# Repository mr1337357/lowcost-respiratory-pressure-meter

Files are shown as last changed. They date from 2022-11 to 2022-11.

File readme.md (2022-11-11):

# Low Cost Respiratory Pressure Meter

[Original Paper](https://www.ncbi.nlm.nih.gov/pmc/articles/PMC8427661/#:~:text=The%20MIP%2FMEP%20device%20should,1%2Ds%20average%20maximum%20pressure)

My dad asked me to help him build a device he found in a science paper and I have ideas for how I want to change it. This is a repo for that.

## licenses

Hardware designs are CERN OHL v1.2  
Software designs are GPL v3

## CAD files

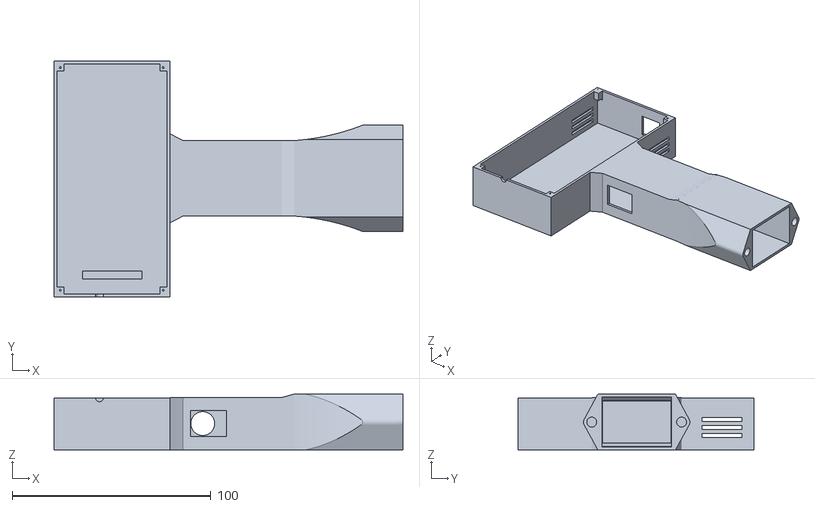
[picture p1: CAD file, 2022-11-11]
printables/electronics case.stl
175.7 x 118.6 x 28.0

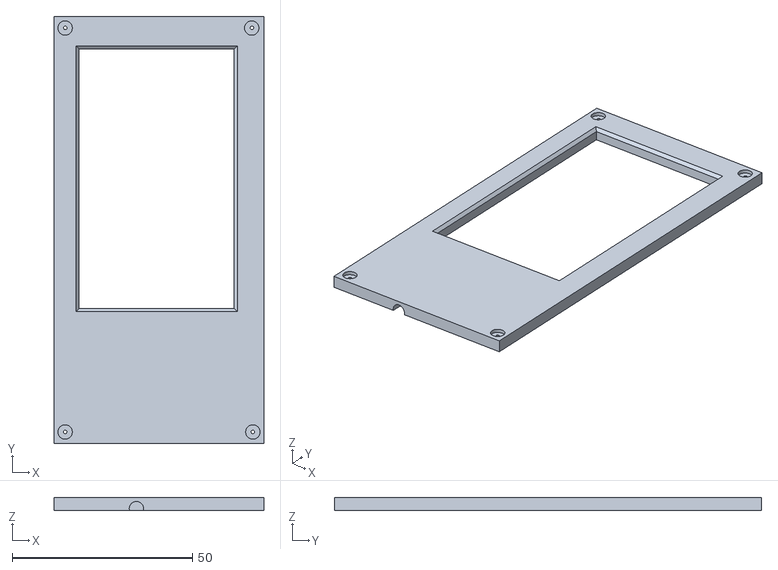
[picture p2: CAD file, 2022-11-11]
printables/screen bezel.stl
58.3 x 118.6 x 3.50

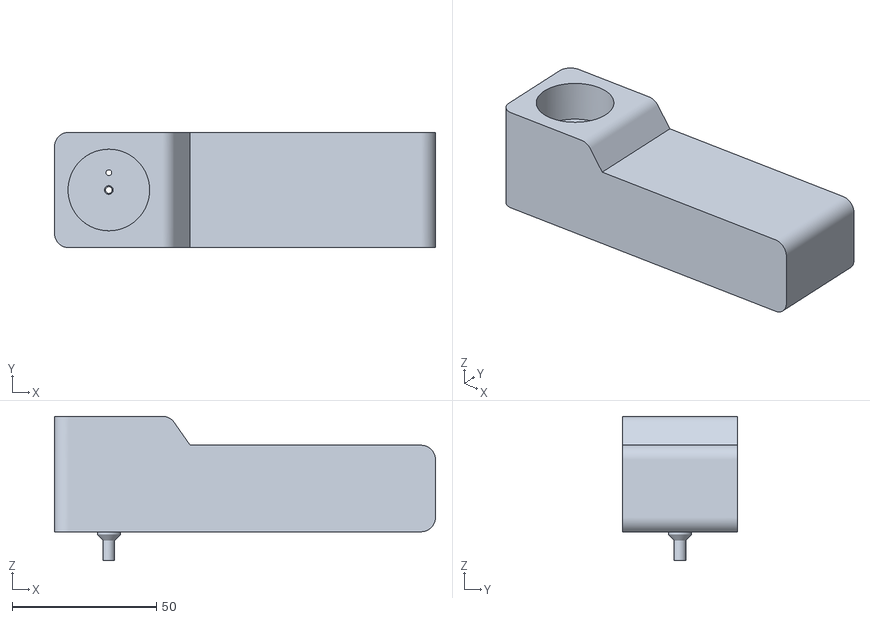
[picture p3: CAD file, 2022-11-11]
printables/handle.stl
132.0 x 40.0 x 50.0

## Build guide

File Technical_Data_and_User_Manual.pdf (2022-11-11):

## OPEN SOURCE HARDWARE PUBLICATION

## TECHNICAL DESCRIPTION

LOW-COST OPEN-SOURCE DEVICE TO MEASURE MAXIMAL

INSPIRATORY AND EXPIRATORY PRESSURES

Claudia Aymerich¹

, Miguel Rodríguez-Lázaro¹

, Gorka Solana²
, Ramon

Farré¹,3,4, Jorge Otero¹,3, *

1 Unitat de Biofísica i Bioenginyeria, Facultat de Medicina i Ciències de la

Salut, Universitat de Barcelona, Barcelona, Spain.

2 Faculdade de Engenharias e Tecnologias, Universidade Save -

Moçambique

3 CIBER de Enfermedades Respiratorias, Madrid, Spain

4
Institut d’Investigacions Biomediques August Pi Sunyer, Barcelona, Spain

*Corresponding author:

Dr. Jorge Otero

Unitat de Biofísica i Bioenginyeria

Facultat de Medicina i Ciències de la Salut

Casanova 143, 08028 Barcelona, Spain

Email: jorge.otero@ub.edu

## LICENSE:

This device is released under CERN Open Hardware License (OHL)

v1.2 and all software and documentation under GNU General Public

License (GPL) v3.0.

Content:

### 1. Device code 2. Schematics of the circuit 3. PCB board layout 4. Connections 5. Enclosure by 3D printer 6. User manual

### 1. Device code

Source code in file: CODE_Arduino.ino (included in the same zip folder where this pdf file is located).

DISCLAIMER

This document provides technical information on the specific device

prototype described in the publication indicated above.

Using components different from (although similar to) the ones described

here may require technical adjustments or adaptations and therefore the

final performance of the resulting device must be specifically assessed.

The authors of this document are not responsible for the use of the

information contained herein nor for any device built using such

information.

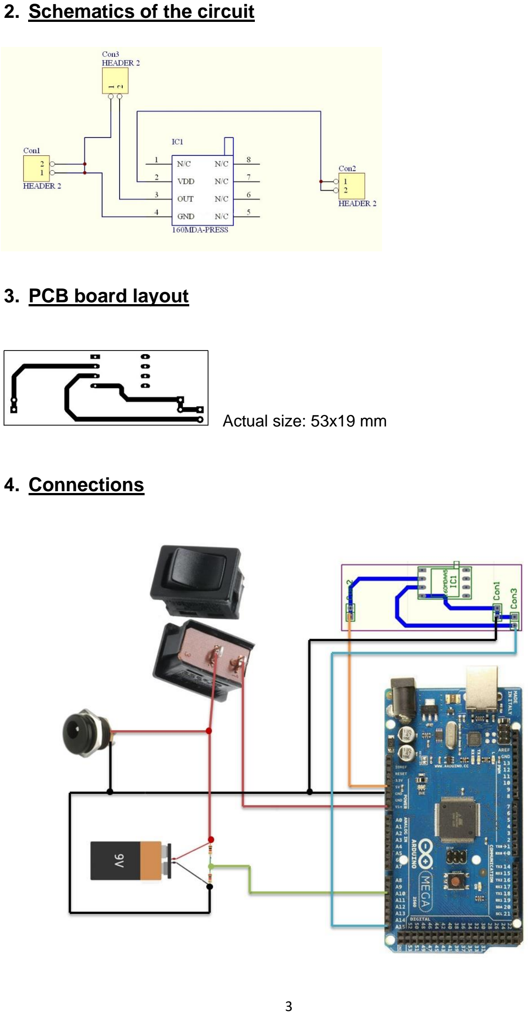
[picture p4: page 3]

### 2. Schematics of the circuit

### 3. PCB board layout

Actual size: 53x19 mm

### 4. Connections

### 5. Enclosure by 3D printing

Source code in files: 3D-file1.stl, 3D-file2.stl, 3D-file3.stl (included in the same zip folder where this pdf file is located).

- Framework

It consists on a rectangular block, adapted to the dimensions of the Arduino, LCD

shield and the PCB, united to the handle block and a cover. The rectangular block

contains some slots for ventilation to avoid the Arduino board overheating, 4 supports

for the screws, 1 support to avoid the Arduino to move, a small slot for the connection

of the transducer to the silicon tube and a hole for the USB type B port of the

Arduino. To optimize the device, it was determined to place the battery in the handle.

The 9V block and its support had perfect dimensions to adapt to this idea. In this

way, the battery could easily be removed from the bottom of the handle. The handle

contains a hole, as well, to place the power switch and another one to place the

supply base. Finally, the cover contains the holes for the screws, the transducer slot

and a rectangular hole adapted to the dimensions of the visible part of the LCD.

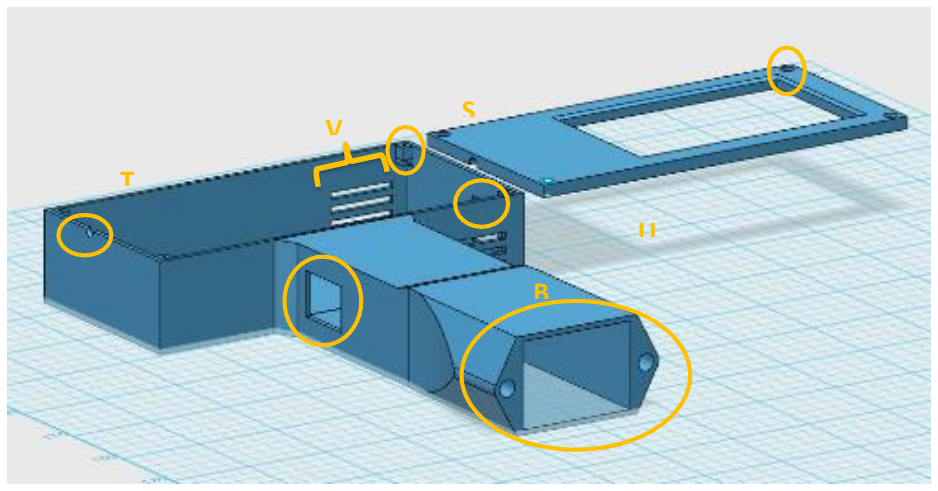
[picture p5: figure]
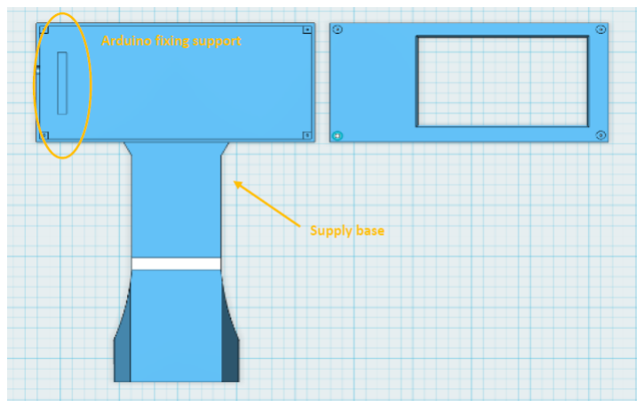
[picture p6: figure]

- Mouthpiece support

It consists of two jointed blocks of different depth. The first block consists on the

handle and the second block is adapted to contain the disposable carton mouthpiece.

Two small holes have been incorporated. The one in the centre connects the air in

the mouthpiece to the transducer along the silicon tube. The second one, on its right,

consist on a small loss of air. It is required to prevent closure of the glottis during

forced inspiration and decreased use of the oral muscles during forced expiration.

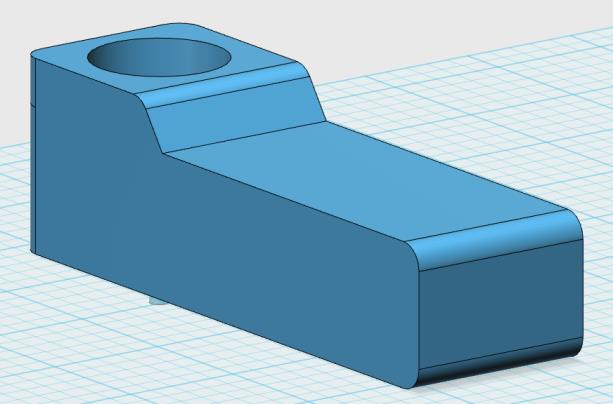
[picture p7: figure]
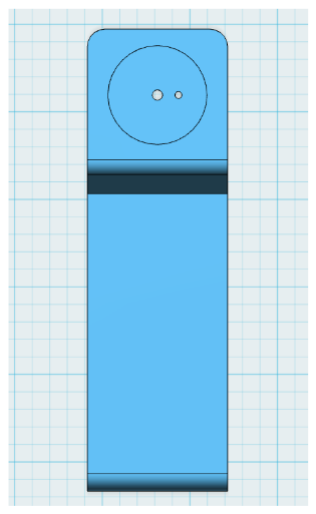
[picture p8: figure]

### 6. User manual

## DEVICE TO MEASURE

## MAXIMAL INSPIRATORY AND EXPIRATORY PRESSURES (MIP / MEP)

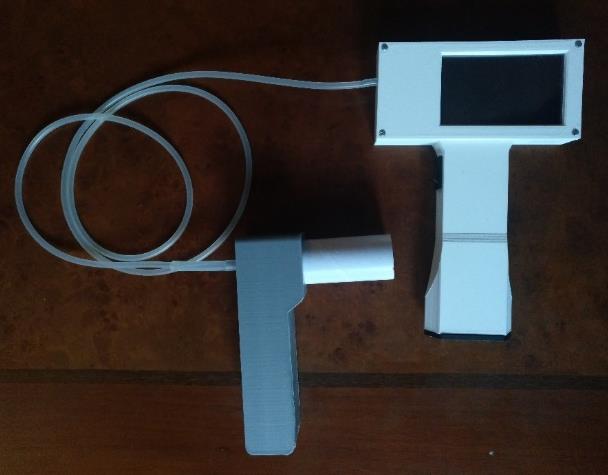
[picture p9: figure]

### 0. Prior instructions

Place a disposable mouthpiece on the corresponding holder and give it to the patient.

### 1. Home screen

Press the switch to start the device. Then, press the button of the test you want to perform. Options to choose from:

-MIP test (Measurement of maximum inspiratory pressure)

-MEP test (Measurement of maximum expiratory pressure)

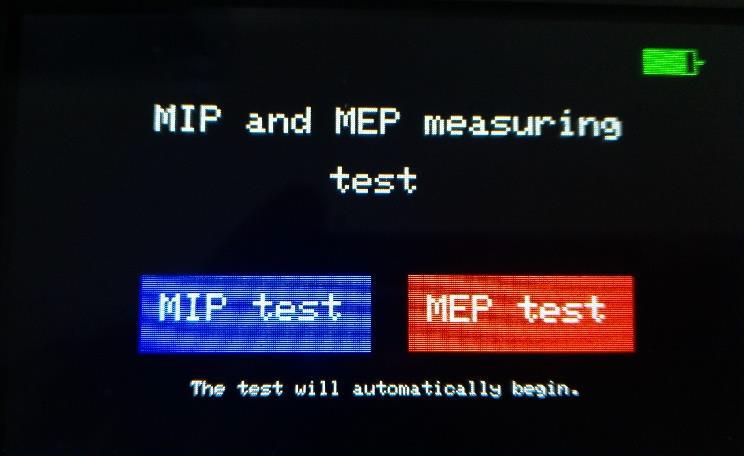
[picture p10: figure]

Figure 1. Home screen

If you choose a wrong button, you will not be able to change the test until step 3.

### 2. Carrying out the test

Have the patient perform the maximum inspiration (or expiration) maneuver. It must last at least 1 second. The maximum time to perform the test is 5 seconds. The screen will display the maximum inspiratory (or expiratory) pressure value of the measurement performed (Figure 2).

If the maneuver has been done correctly, you should observe a curve similar to that in Figure 3. In this case, press the "Accept" button. The measurement will be saved in the device memory. To reject the measurement, press the "Reject" button.

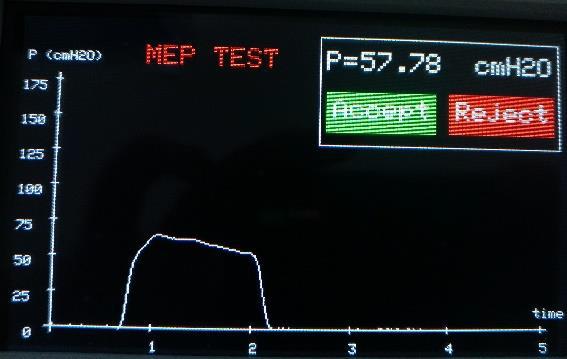
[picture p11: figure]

Figure 2. Test run

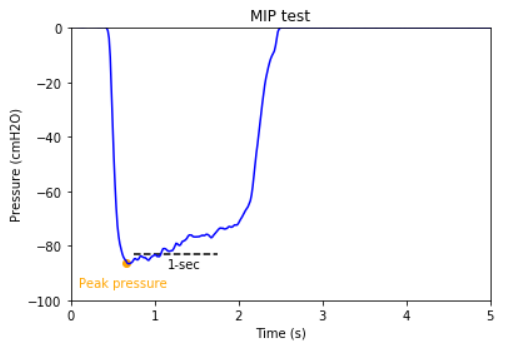
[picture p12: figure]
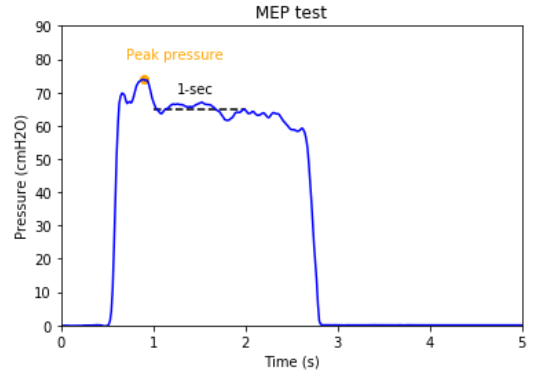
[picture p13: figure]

Figure 3. Illustration of correct MEP (Pemax) and MIP (Pimax) measurements

### 3. Repetition of the test

To perform the next test, press the “Next measure” button and repeat the procedure in point 2. You will see that, as you perform valid tests, the pressure values of the previous measurements will appear on the right side of the screen.

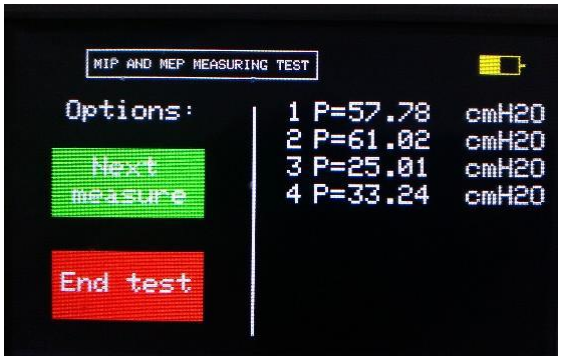
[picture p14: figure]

Figure 4. Screen at the end of a measurement

If you want to change the experiment or end the experiment, press the "End test" button. This button will direct you to step 5.

### 4. Completion of the MIP / MEP test

In the case of performing three measurements that differ by less than 10%, the device will indicate the value of MIP or MEP of that patient, as shown in Figure 5. In addition, at the bottom- on the right side of the screen you will see the three pressure values used to calculate the MIP / MEP.

The measure is terminated. The oprator can then record this value into the patient's medical record. Press the "End test" button to exit the screen. This button will direct you to step 5.

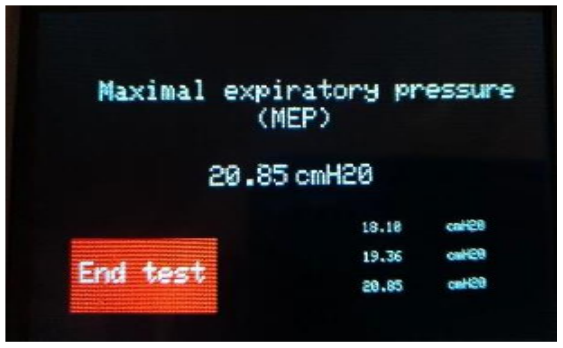
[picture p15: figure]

Figure 5. Example of MEP value

If you do not get three measures that differ by less than 10%, if the oprator deems it appropriate, he/she can end the test without the device telling you what the patient's MIP or MEP is. The specialist can take note of the pressure values generated in each of the valid measures to introduce them into the patient's medical history. These values are on the right of the screen, in the form of a list (see Figure 4).

Finally, select the "End test" button.

### 5. Test change and / or device shutdown

If you want to change the experiment, press the "Change" button. The initial screen will appear again, in which you can choose the test to be performed (MIP or MEP).

If you want to finish the test for good, press the "Off" button. The following message will appear: "Thank you". Finally press the power switch to turn off the device.

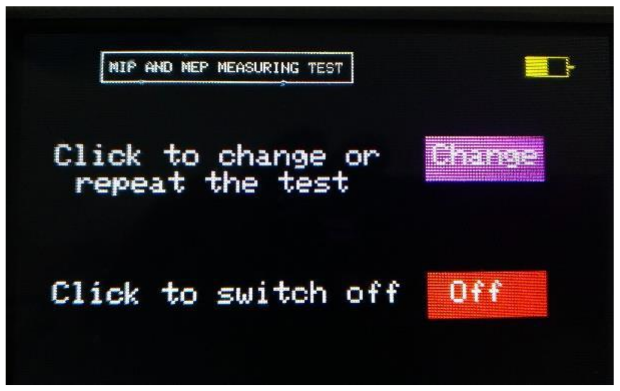
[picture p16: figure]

Figure 6. Test change and device shutdown

### 6. Battery

The battery status of the device is indicated at the top-right of the screen, on all screens except the measurement (graphic) screen. Battery status is divided into five levels:

The battery is in its maximum state of charge.

The battery has more than 50% charge

The battery is between 25% and 50% charge

The battery is at less than 25% charge

In this state, the message “Charge” appears on the screen. The device will take a few minutes to turn off.

It is recommended to charge the device if the battery icon is yellow to ensure that you have enough battery power for the next measurement, as the maximum battery life, when fully charged, is one hour. The charger comes bundled with the device, along with a time controller. It is important that the charger is connected to the time controller (which comes fixed to the base for 2 hours of charging) as otherwise the device could be damaged.

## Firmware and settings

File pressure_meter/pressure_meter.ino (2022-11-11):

///////////////////////////////////////////////////CODI TFG CLAUDIA AYMERICH/////////////////////////////////////////////////////


///////////////////////////////////////////LLIBRERIES///////////////////////////////////////////////////////////////////////////
#include <SPI.h> //libreries de la SD
#include <SD.h>

// Llibreries del tft
//#include <Adafruit_TFTLCD.h> // Core graphics library
#include <Adafruit_GFX.h>    // Hardware-specific library
#include <TouchScreen.h>
#include <MCUFRIEND_kbv.h>
MCUFRIEND_kbv tft;

////////////////////////////////////////DEFINICIONS/////////////////////////////////////////////////////////////////////////////
// we define the pins used by the LCD display
#define LCD_CS A3 
#define LCD_CD A2 
#define LCD_WR A1 
#define LCD_RD A0 
#define LCD_RESET A4 

#define SD_SCK 13
#define SD_MISO 12
#define SD_MOSI 11
#define SD_CS 5

// values found by screen calibration (feta per mi)
#define TS_MINX 129 //from calibration: x of right-lower corner
#define TS_MINY 127
#define TS_MAXX 938 //from calibration: x of left-upper corner
#define TS_MAXY 897


#if defined(__SAM3X8E__)
#undef __FlashStringHelper::F(string_literal)
#define F(string_literal) string_literal
#endif
// define the pins used to activate the touch screen
uint8_t YP = A1;  // must be an analog pin, use "An" notation!
uint8_t XM = A2;  // must be an analog pin, use "An" notation!
uint8_t YM = 7;   // can be a digital pin
uint8_t XP = 6;   // can be a digital pin
uint8_t SwapXY = 0;

uint16_t TS_LEFT = 880;
uint16_t TS_RT  = 170;
uint16_t TS_TOP = 950;
uint16_t TS_BOT = 180;
char *name = "Unknown controller";

// define color codes
#define BLACK   0x0000
#define BLUE    0x001F
#define RED     0xF800
#define GREEN   0x07E0
#define CYAN    0x07FF
#define MAGENTA 0xF81F
#define YELLOW  0xFFE0
#define WHITE   0xFFFF
#define ORANGE  0xE880

// fixed definition used by TFT LCD library
//Adafruit_TFTLCD tft(LCD_CS, LCD_CD, LCD_WR, LCD_RD, LCD_RESET);

// fixed definition used by Touch Screen library
TouchScreen ts = TouchScreen(XP, YP, XM, YM, 300);
TSPoint tp;

///////////////////////////////////////////////////////VARIABLES/////////////////////////////////////////////////////
//Definim les variables
int FileToOpen = 1; 
char newfile[10]=" ";
byte t=0, k, a=0, indexMAX=3, indexMIN=0, b=0, dibuix=0, tipo=0, next=0, variable=1;
int px, py, counter=0, j, altura, contador=0, contacceptar=0;
float oldValueMIP=0, oldValueMEP=0, Value,maxim=0, minim=110, mitja, suma, holder;
// if we touch the red button, the program will display a message
boolean buttonEnabled1 = true; //MIP/MEP initial buttons
boolean buttonEnabled2= false; //next measurement
boolean buttonEnabled3= false; //stop
boolean buttonEnabled6= false; //Accept MIP
boolean buttonEnabled7= false; //Reject MIP
boolean buttonEnabled8= false; //Accept MEP
boolean buttonEnabled9= false; //Reject MEP
boolean buttonEnabled10= false; //change test
boolean buttonEnabled11= false; //off
int sensorPin = A15;
int batteryPin= A11;
int bat=0;
unsigned long interval=1000/70;// canvi (els llocs on posa canvi s'han de canviar si es canvia la freq)
unsigned long previousMillis=0; // millis() returns an unsigned long.
float myArray[350]; //70Hz
float mitjanes[12]={200,200,200,200,200,200,200,200,200,200,200,200}; //vector on guardarem les dades de la mitja 
//(el posem a 200 per tenir els valors obtinguts al principi del vector en ordre 
//creixent i així no fer una mitja amb els valors previs no obtinguts de l'experiment)
float pressions[12]; //vector on guardarem les dades de pressions per anar imprimint-los a mesura que s'accepten 


/////////////////////////////////////////////DIBUIX DE LES PANTALLES////////////////////////////////////////////////////
//Dibuix de la pantalla inicial
void startScreen(){
  tft.setCursor(75,50); //set cursor, default 0,0.Is placed in the top left corner: per dir on vols posar el text
  tft.setTextColor(WHITE); //set text color
  tft.setTextSize(2); //set text size (default is 1, also 2 and 3)
  tft.println("MIP and MEP measuring\n\n              test"); //print like in serial or println

  //drawing of MIP button
  tft.fillRect(70,140, 120, 40, BLUE); //rectangle of a certain width and height (x0,y0,w,h,color)
  tft.drawRect(70,140,120,40,BLUE); //frame
  tft.setCursor(80,150);
  tft.setTextColor(WHITE);
  tft.setTextSize(2);
  tft.print("MIP test");

  //drawing of MEP button
  tft.fillRect(210,140, 120, 40, RED); 
  tft.drawRect(210,140,120,40,RED);
  tft.setCursor(220,150);
  tft.print("MEP test");
}

//Dibuix dels botons de tot el programa
void NextMeasure(){ 
  tft.fillRect(30,85,110,50,GREEN);
  tft.drawRect(30,85,110,50,GREEN); //frame
  tft.setTextColor(WHITE);
  tft.setTextSize(1);
  tft.setCursor(60,20);
  tft.print("MIP AND MEP MEASURING TEST"); 
  tft.drawRect(54,13,168,21,WHITE);
  tft.setTextSize(2);
  tft.setCursor(40,50);
  tft.print("Options:");
  tft.drawRect(175,54,2,166,WHITE);
  tft.setCursor(60,91);
  tft.print("Next");
  tft.setCursor(45,111);
  tft.print("measure");
}

void Stop(){
  tft.fillRect(30,160,110,50,RED);
  tft.drawRect(30,160,110,50,RED);
  tft.setCursor(37,175);
  tft.setTextColor(WHITE);
  tft.setTextSize(2);
  tft.print("End test");
}

void MEPvalue(){
  tft.fillScreen(BLACK);
  tft.setCursor(50,50);
  tft.setTextSize(2);
  tft.setTextColor(WHITE);
  tft.print("Maximal expiratory pressure"); 
  tft.setCursor(170,70);
  tft.print("(MEP)");   
}

void MIPvalue(){
  tft.fillScreen(BLACK);
  tft.setCursor(40,50);
  tft.setTextSize(2);
  tft.setTextColor(WHITE);
  tft.print("Maximal inspiratory pressure"); 
  tft.setCursor(170,70);
  tft.print("(MIP)");   
}


void AcceptMIP(){
  tft.fillRect(220,200, 80, 30, GREEN);
  tft.drawRect(220,200,80,30,GREEN); //frame
  tft.setCursor(225,205);
  tft.setTextColor(WHITE);
  tft.setTextSize(2);
  tft.print("Accept");
  tft.drawRect(215,162,180,74,WHITE);  
  
}

void RejectMIP(){
  tft.fillRect(310,200, 80, 30, RED);
  tft.drawRect(310,200,80,30,RED); //frame
  tft.setCursor(315,205);
  tft.print("Reject");  
  
}

void AcceptMEP(){
  tft.fillRect(220,50, 80, 30, GREEN);
  tft.drawRect(220,50,80,30,GREEN); //frame
  tft.setCursor(225,55);
  tft.setTextColor(WHITE);
  tft.print("Accept");  
  tft.drawRect(215,10,180,80,WHITE);
}

void RejectMEP(){
  tft.fillRect(310,50, 80, 30, RED);
  tft.drawRect(310,50,80,30,RED); //frame
  tft.setCursor(315,55);
  tft.print("Reject");  
}

void ChangeTest(){
  tft.fillRect(270,70,80,30,MAGENTA);
  tft.drawRect(270,70,80,30,MAGENTA); //frame
  tft.setTextColor(WHITE);
  tft.setTextSize(1);
  tft.setCursor(25,98);
  tft.print("The test will automatically begin."); 
  tft.setCursor(60,20);
  tft.print("MIP AND MEP MEASURING TEST"); 
  tft.drawRect(54,13,168,21,WHITE);
  tft.setCursor(275,75);
  tft.setTextSize(2);
  tft.print("Change"); 
  tft.setCursor(25,75);
  tft.print("Click to change test"); 
}

void Off(){
  tft.fillRect(270,160,80,30,RED); 
  tft.drawRect(270,160,80,30,RED); //frame 
  tft.setCursor(25,165);
  tft.setTextColor(WHITE);
  tft.print("Click to switch off"); 
  tft.setCursor(285,165);
  tft.print("Off");
}

void FinalScreen(){
  tft.setTextColor(WHITE);
  tft.setCursor(140,110);
  tft.print("Thank you");
}

//////////////////////////////////////DIBUIX EIXOS GRAFIQUES///////////////////////////////////////
//Dibuix dels eixos de MEP
void drawGraphMEP(){
  tft.fillScreen(BLACK);
  tft.setTextSize(2);
  tft.setTextColor(RED);
  tft.setCursor(90,20);
  tft.print("MEP TEST");
  tft.drawLine(24, 220, 382, 220, WHITE); //Eix x (starting and ending point) afegim 78 punts
  tft.drawLine(28, 41, 28, 224, WHITE); //Eix y
  tft.setCursor(5,25);
  tft.setTextSize(1);
  tft.setTextColor(WHITE);
  tft.print(F("P (cmH2O)"));
  tft.setCursor(373, 205);
  tft.print("time");

//Ticks en eix y: nombre
  j=175;
  for (int i=45; i <=206; i=i+25){ //cada pixel és un punt
    tft.drawLine(26,i,30,i,WHITE); //x: dos abans i dos després, i igual pq mateixa altura 
    tft.setCursor(2, i+2); //i+2 pq el pal no es mengi el numero
    tft.print(j);
    j=j-25; 
  }

  //Ticks en eix x
  k=1;
  for (int m=98; m <=379; m=m+70){ //98 és el segon 1 és on comença la linia gran
    tft.drawLine(m,218,m,222,WHITE); //x: dos abans i dos després, i igual pq mateixa altura 
    tft.setCursor(m, 230); //m+2 pq el pal no es mengi el numero
    tft.print(k);
    k=k+1; 
  }
  //Tick origen
  tft.setCursor(10,222);
  tft.print("0"); //origen   
}

//Dibuix dels eixos de MIP
void drawGraphMIP(){
  tft.fillScreen(BLACK);
  tft.setTextSize(2);
  tft.setTextColor(BLUE);
  tft.setCursor(90,205);
  tft.print("MIP TEST");
  tft.drawLine(24, 20, 382, 20, WHITE); //Eix x 
  tft.drawLine(28, 16, 28, 199, WHITE); //Eix y
  tft.setCursor(5,215);
  tft.setTextSize(1);
  tft.setTextColor(WHITE);
  tft.print(F("P (cmH2O)"));
  tft.setCursor(373, 35);
  tft.print("time");

//Ticks en eix y
  j=-25;
  for (int i=45; i <=196; i=i+25){ //12 és on comença la linia gran
    tft.drawLine(26,i,30,i,WHITE); //x: dos abans i dos després, i igual pq mateixa altura 
    tft.setCursor(2, i+2); //i+2 pq el pal no es mengi el numero
    tft.print(j);
    j=j-25; 
  }

//Ticks en eix x
k=1;
  for (int m=98; m <=379; m=m+70){ //12 és on comença la linia gran
    tft.drawLine(m,18,m,22,WHITE); //x: dos abans i dos després, i igual pq mateixa altura 
    tft.setCursor(m, 6); //m+2 pq el pal no es mengi el numero
    tft.print(k);
    k=k+1; 
  }

//Tick origen
  tft.setCursor(10,22);
  tft.print("0");   
}

////////////////////////////////////DIBUIX ESTATS BATERIA/////////////////////////////////////
//Poses void en una funció quan no ha de retornar res
void LowBattery(){
  //tft.fillRect(150,110,50,10,BLACK);
  //tft.fillRect(320,15,80,14,BLACK);
  tft.setTextColor(WHITE);
  tft.fillRect(340,15,5,14,RED);
  tft.drawRect(340,15,30,14,RED);
  tft.fillRect(370,21,4,2, RED);
}

void OrangeBattery(){
  //tft.fillRect(320,15,80,14,BLACK);
  tft.setTextColor(WHITE);
  tft.fillRect(340,15,15,14,YELLOW);
  tft.drawRect(340,15,30,14,YELLOW);
  tft.fillRect(370,21,4,2, YELLOW);
}

void GreenBattery(){
  //tft.fillRect(320,15,80,14,BLACK);
  tft.setTextColor(BLACK);
  tft.fillRect(340,15,30,14,GREEN);
  tft.drawRect(340,15,30,14,GREEN);
  tft.fillRect(370,21,4,2, GREEN);
}

void AllBattery(){
  //tft.fillRect(320,15,80,14,BLACK);
  tft.setTextColor(GREEN);
  tft.setCursor(340,15);
  tft.print("100%");
}

void Charge(){
  //tft.fillRect(320,15,80,14,BLACK);
  tft.setTextColor(RED);
  tft.setCursor(320,15);
  tft.print("CHARGE");
}



///////////////////////////////////////SETUP//////////////////////////////////////////////////////////////////////
void setup(void) {
  Serial.begin(9600);
  tft.reset(); // for starting communication of the TFT LCD Touch Screen
  uint16_t identifier = tft.readID();
  tft.begin(identifier);
  tft.setRotation(3); // rotating the display: done once in the setup, parameters: 0,1,2,3 (0,90,180 or 270 deg)
  tft.fillScreen(BLACK); //filling color of screen 
  startScreen(); //cridem pantalla principal (només es pot fer un cop)
  //BatteryState(batteryPin);   
}

////////////////////////////////////////////LOOP///////////////////////////////////////////////////////////
void loop() {  
  // put your main code here, to run repeatedly:
  tp = ts.getPoint(); //if we touch the red button, the program will display a message
  pinMode(XM, OUTPUT); //pin mode required for the libray
  pinMode(YP, OUTPUT);
  pinMode(XP, OUTPUT);
  pinMode(YM, OUTPUT);

  if (bat==0){
    //tft.setCursor(320,15);
    //tft.setTextColor(RED);
    //tft.print("hola");
    BatteryState(batteryPin);}
  
  

  //aquesta part involucra la part tàctil i els botons: s'han d'activar i desactivar quan toca
  if (tp.z > ts.pressureThreshhold) { //he de mirar quin és aquest threshold
    
   //tp.x = map(tp.x, TS_MINX, TS_MAXX, 0, 240); //map:convert the values got from the touch screen library in pixels
   //tp.y = map(tp.y, TS_MINY, TS_MAXY, 0, 400); //is the resolution of the screen we use in pixels
   //px = tp.y; //fem això per adequar tàctil amb posició de la pantalla que s'ha triat
   //py = tp.x;
   tp.x = map(tp.x, TS_LEFT, TS_RT,0,240);
   tp.y = map(tp.y, TS_TOP, TS_BOT,400,0 );
   px = tp.y; //fem això per adequar tàctil amb posició de la pantalla que s'ha triat
   py = tp.x;
   //Click butons de la pantalla incial
   
   //MEP button    
   if(px>210 && px<330 && py>140 && py<180 && buttonEnabled1){ //now we know the x,y values of the touch point
    //in pixels to male clickable buttons: if we touch the screen within these coordinates, button activated
    buttonEnabled1 = false; //we deactivate the button coordinates for the next page
    t=1;
    bat=1;
    drawGraphMEP();  
    }
   
       //MIP button    
   if(px>70 && px<190 && py>140 && py<180 && buttonEnabled1){ //now we know the x,y values of the touch point
    //in pixels to male clickable buttons: if we touch the screen within these coordinates, button activated
    buttonEnabled1 = false; //we deactivate the button coordinates for the next page
    //Aquí hauria de canviar una variable que et fes portar a la següent pantalla.
    t=2;
    bat=1;
    drawGraphMIP();
   }

   //quan acaba la mesura de MEP surten opcions acceptar i rebutjar, que porten a un altra pantalla
   if (next==1){ 
    contador=0, a=0, indexMAX=3, indexMIN=0, b=0, dibuix=0;
    counter=0; pressions[0]=0;
    oldValueMIP=0, oldValueMEP=0, Value,maxim=0, minim=110; 
    
    if(px>220 && px<300 && py>50 && py<80 && buttonEnabled8){  //cas d'acceptar: guardarem a sd. Parlar quines dades volen guardar exactament
      buttonEnabled8 = false; //acceptar
      buttonEnabled9=false; //rebutjar

      
      //discrepar max 10%
      contacceptar++;
      mitjanes[contacceptar] = mitja;
      pressions[contacceptar]=mitja;


      //ordenem en ordre creixent els valors obtinguts (en funció d'anar-los obtenint)
      for(byte x = 0; x < sizeof(mitjanes)/sizeof(float); x++)
        for(byte y = 0; y < sizeof(mitjanes)/sizeof(float)-1; y++)
          if(mitjanes[y] > mitjanes[y+1]  ) {
          holder = mitjanes[y+1];
          mitjanes[y+1] = mitjanes[y];
          mitjanes[y] = holder;
     }
      
     Serial.println("contador acceptar");
     Serial.println(contacceptar);
     if (contacceptar<3){ 
      variable=1; //aparegui la opció de next measurement
     }
     if (contacceptar>2){ //s'inicia el càlcul de la mitja de tres valors un cop tens tres valors (per evitar promitjar amb el valor 200 predefinit al array)
      for (int z=1; z <contacceptar-1; z++){
        float xvalue=mitjanes[z];
        Serial.print("xvalue");
        Serial.println(xvalue);
        Serial.println(xvalue-0.1*xvalue);
        Serial.println(xvalue+0.1*xvalue);
        if ((xvalue-0.1*xvalue)<mitjanes[z-1] && mitjanes[z-1]<(xvalue+0.1*xvalue)&& (xvalue-0.1*xvalue)<mitjanes[z+1] && mitjanes[z+1] <(xvalue+0.1*xvalue)){ 
          //el valor anterior i el posterior han d'estar compresos en l'interval corresponent (si no és el cas amb el segon valor es mira pel tercer, el quart fins comprovar per tots els packs de valors del vector)
          float valor1=mitjanes[z-1];
          float valor2=xvalue;
          float valor3=mitjanes[z+1];
          float MEP=valor3; //màxim dels tres valors
          //float MEP=(mitjanes[z-1]+xvalue+mitjanes[z+1])/3; //mitja dels tres valors 
          Serial.println("MEP final");
          Serial.println(MEP);

          z=contacceptar-1; //si trobem un valor per fer el MEP (3 valors q discrepen menys del 10%) parem el bucle per no seguir buscant més
          variable=2; //eliminem la opció next measurement
          MEPvalue();
          tft.setTextColor(WHITE);
          tft.setCursor(135,110);
          tft.print(MEP); 
          tft.setCursor(200,110);
          tft.print("cmH20");
          
          
          //print de les tres mesures utilitzades per calcular el MEP
          tft.setTextSize(1);
          tft.setCursor(250,150);
          tft.print(valor1);
          tft.setCursor(315,150);
          tft.print("cmH20");
          tft.setCursor(250,170);
          tft.print(valor2);
          tft.setCursor(315,170);
          tft.print("cmH20");
          tft.setCursor(250,190);
          tft.print(valor3);
          tft.setCursor(315,190);
          tft.print("cmH20");

          
          Stop();
          buttonEnabled2=false; //eliminem la opció next measurement
          buttonEnabled3 = true; //l'opció end test segueix present
          
        }
        else{
          Serial.println("Fes una altra mesura");
          Serial.println(z);
          variable=1; // si no hi ha tres valors q discrepen menys del 10% surt opció next measurement
    }
      }
     }
     
      if (variable==1){
      tft.fillScreen(BLACK);
      bat=0;
      NextMeasure();
      Stop();
      
      buttonEnabled2=true;
      buttonEnabled3 = true;
      tft.setTextColor(WHITE);
      tft.setTextSize(2);

      //Dibuix pressions a la pantalla next measurement cas acceptar MEP
  altura=50;
  for (int i=1; i <=contacceptar; i=i+1){ 
      tft.setCursor(220,altura); 
      tft.print(F("P="));
      tft.setCursor(330,altura);
      tft.print(F("cmH2O")); 
      tft.setCursor(245,altura);
      tft.print(pressions[i]);
      tft.setCursor(200,altura);
      tft.print(i);
      altura=altura+20;
      }
      }

      //això serveix per anar mirant com evoluciona el vector mitjanes en funció de l'obtenció de valors
      Serial.println ("valors");
      for(int i = 0; i < sizeof(mitjanes)/sizeof(float); i++)
      {
      Serial.println(mitjanes[i]);
      }
    }
    
    if(px>310 && px<390 && py>50 && py<80 && buttonEnabled9){ //cas de rebutjar: no guardarem a sd
      buttonEnabled8 = false;
      buttonEnabled9 = false;
      //nosdprint
      Serial.print("Reject");
      tft.fillScreen(BLACK);
      bat=0;
      NextMeasure();
      Stop();
       
      buttonEnabled2=true;
      buttonEnabled3 = true;
      tft.setTextColor(WHITE);
      tft.setTextSize(2);
       //Dibuix pressions a la pantalla next measurement cas rebutjar MEP
  altura=50;
  for (int i=1; i <=contacceptar; i=i+1){ 
      tft.setCursor(220,altura); 
      tft.print(F("P="));
      tft.setCursor(330,altura);
      tft.print(F("cmH2O")); 
      tft.setCursor(245,altura);
      tft.print(pressions[i]);
      tft.setCursor(200,altura);
      tft.print(i);
      altura=altura+20;
      }
  
    }   
   }
   

   //mateix que anterior pel cas del MIP
   if (next==2){ 
    contador=0, a=0, indexMAX=3, indexMIN=0, b=0, dibuix=0;
    counter=0; pressions[0]=0;
    oldValueMIP=0, oldValueMEP=0, Value,maxim=0, minim=110; 

    if(px>220 && px<300 && py>200 && py<230 && buttonEnabled6){ //cas d'acceptar: guardarem a sd  
      buttonEnabled6 = false;
      buttonEnabled7=false;

      
      contacceptar++;
      mitjanes[contacceptar] = mitja;
      pressions[contacceptar]=mitja;

      for(byte x = 0; x < sizeof(mitjanes)/sizeof(float); x++)
        for(byte y = 0; y < sizeof(mitjanes)/sizeof(float)-1; y++)
          if(mitjanes[y] > mitjanes[y+1]  ) {
          holder = mitjanes[y+1];
          mitjanes[y+1] = mitjanes[y];
          mitjanes[y] = holder;
     }

     Serial.println("contador acceptar");
     Serial.println(contacceptar);
     if (contacceptar<3){
      variable=1;
     }
     if (contacceptar>2){ //////////////////////////////////////////////////////////////////////////////////////////////////////////
      for (int z=1; z <contacceptar-1; z++){
        float xvalue=mitjanes[z];
        Serial.print("xvalue");
        Serial.println(xvalue);
        Serial.println(xvalue-0.1*xvalue);
        Serial.println(xvalue+0.1*xvalue);
        if ((xvalue-0.1*xvalue)>mitjanes[z-1] && mitjanes[z-1]>(xvalue+0.1*xvalue)&& (xvalue-0.1*xvalue)>mitjanes[z+1] && mitjanes[z+1] >(xvalue+0.1*xvalue)){
          float valor1=mitjanes[z-1];
          float valor2=xvalue;
          float valor3=mitjanes[z+1];
          float MIP=valor3;
          Serial.println("MIP final");
          Serial.println(MIP);
          z=contacceptar-1;
          variable=2;
          MIPvalue();
          tft.setTextColor(WHITE);
          tft.setCursor(130,110);
          tft.print(MIP); //desconnectar boto next measure i tornar a connectar quan toqui
          tft.setCursor(210,110);
          tft.print("cmH20");

          //print de les tres mesures utilitzades per calcular el MIP
          tft.setTextSize(1);
          tft.setCursor(250,150);
          tft.print(valor1);
          tft.setCursor(315,150);
          tft.print("cmH20");
          tft.setCursor(250,170);
          tft.print(valor2);
          tft.setCursor(315,170);
          tft.print("cmH20");
          tft.setCursor(250,190);
          tft.print(valor3);
          tft.setCursor(315,190);
          tft.print("cmH20");




          
          Stop();
          buttonEnabled2=false;
          buttonEnabled3 = true;
          
        }
        else{
          Serial.println("Fes una altra mesura");
          Serial.println(z);
          variable=1;
    }
      }
     }
     
      if (variable==1){
      tft.fillScreen(BLACK);
      bat=0;
      NextMeasure();
      Stop();
        /////////////////////////////
      
      buttonEnabled2=true;
      buttonEnabled3 = true;
      tft.setTextColor(WHITE);
      tft.setTextSize(2);


            //Dibuix pressions a la pantalla next measurement cas acceptar MIP
  altura=50;
  for (int i=1; i <=contacceptar; i=i+1){ 
      tft.setCursor(220,altura); 
      tft.print(F("P="));
      tft.setCursor(330,altura);
      tft.print(F("cmH2O")); 
      tft.setCursor(245,altura);
      tft.print(pressions[i]);
      tft.setCursor(200,altura);
      tft.print(i);
      altura=altura+20;
      }
      }
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

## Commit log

2022-11-11 copied data archive from paper
    [3D-file1.stl, 3D-file2.stl, 3D-file3.stl]
2022-11-11 renamed things and added license info
    [electronics case.stl, handle.stl, screen bezel.stl]
